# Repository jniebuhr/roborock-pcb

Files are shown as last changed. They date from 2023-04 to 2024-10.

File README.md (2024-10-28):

# Roborock CPAP PCB


[][cc-by-nc-sa]

This repository contains a custom PCB for use with the awesome work at [Roborock CPAP](https://github.com/condottab/Roborock-CPAP). The PCB shields the controller board from any back flow that might occur from the brushless controller.

The logic is the same as in the work of [stas2z](https://github.com/stas2z) but reshaped to better fit on the back of the blower while also allowing
for a cooling fan to be added.

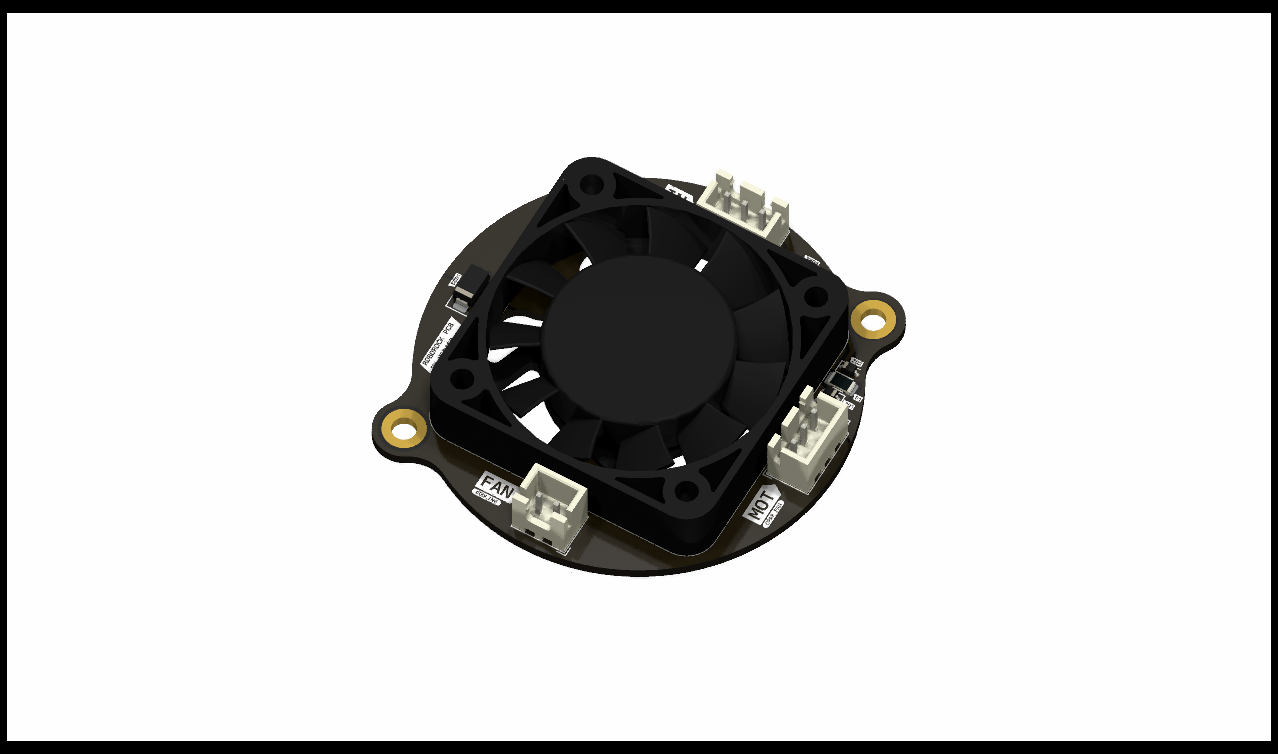
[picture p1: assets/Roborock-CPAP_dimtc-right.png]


## Assembly

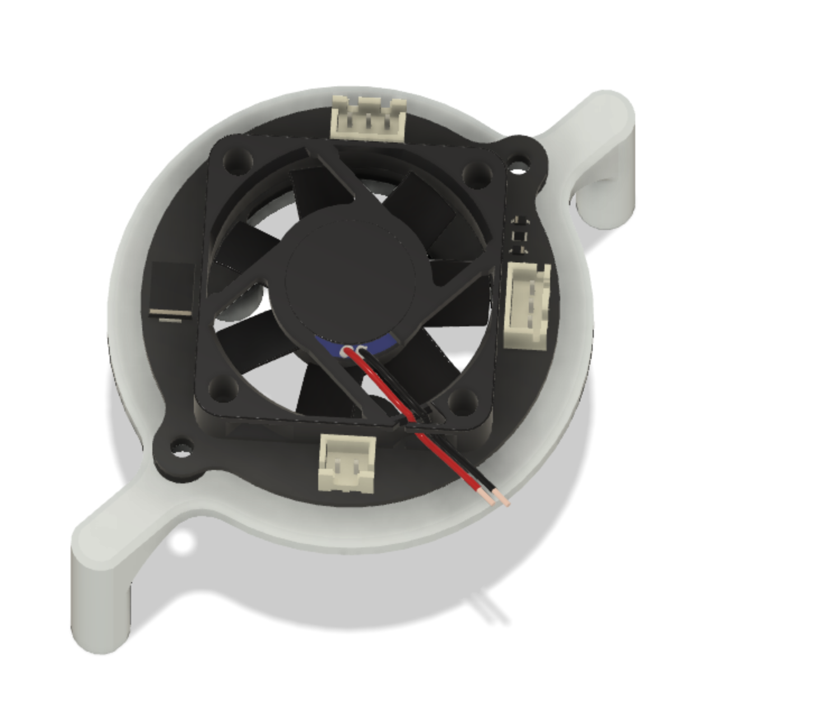
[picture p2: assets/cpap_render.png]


## BOM

| Quantity | Designation | Description |
|---|---|---|
| 1 | SHOTTKY2 | SS34 Diode |
| 2 | SHOTTKY1 | SS54 Diode |
| 1 | ZENER1, ZENER2 | BZT52C5V1S Diode |
| 1 | R2 | 1206 10kΩ resistor |
| 1 | R1 | 1206 1kΩ resistor |
| 2 | J1, J2 | JST XH 3P 2.54mm |
| 1 | J3 | JST XH 2P 2.54mm |
| 1 | - | 4010 cooling fan 24V |
| 2 | - | M3x6 |
| 4 | - | M3x12 |
| 4 | - | M3 hex nut |
| 4 | - | M3 heat set insert |

## Pinout

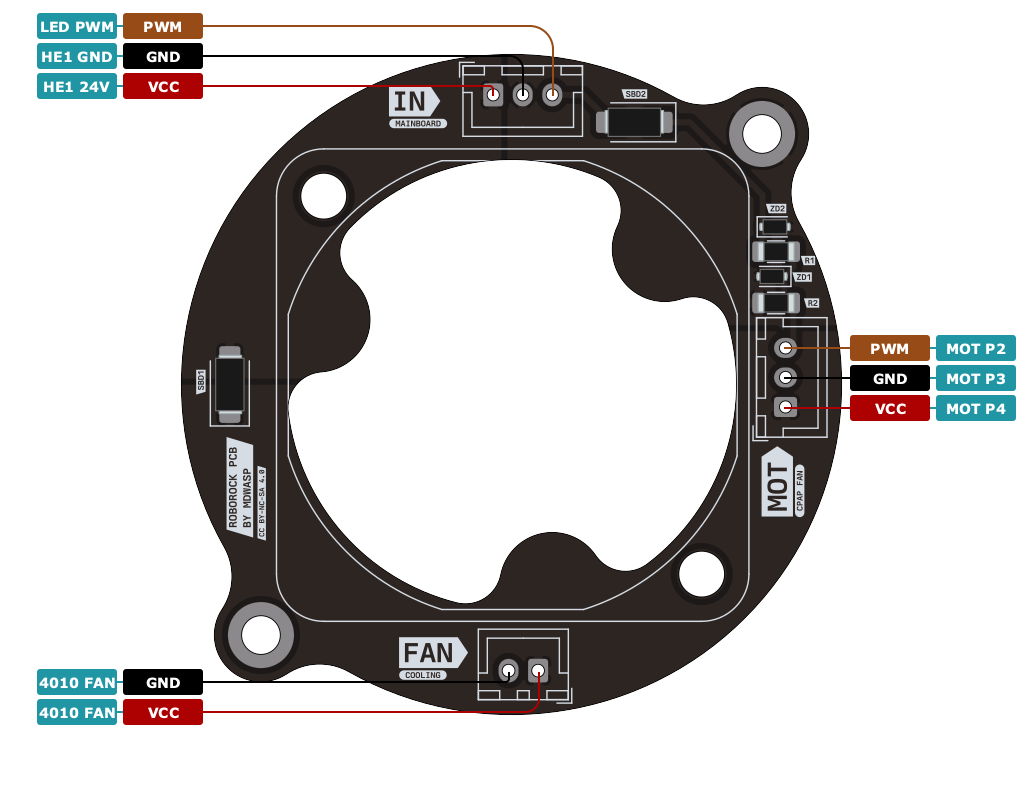
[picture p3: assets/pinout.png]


The pinout can also be found on the back side of your board and may be different from the most recent version (see note below). 

**Attention:**  
This motor pinout changed in version 0.2.0 due to a rotation of a connector. The same cables will work though since the connector has only been rotated. Refer to the writing on the back of your board.
In version 0.2.0, the 2 pin fan connector was labeled with switched GND and VCC.

## Ordering

In order to support this project, please consider ordering it through my affiliate link.

<a href="https://www.pcbway.com/project/shareproject/Roborock_CPAP_PCB_dc4ef951.html">PCB from PCBWay</a>

The gerber and BOM/CPL files can be found under `kicad/`.

## Mounting options

I have also developed some additional mounting options for the Roborock Fan:

* [VzBot 235](mounting/vzbot-235)
* more coming soon...

## Sponsors

The development of this board was kindly supported by [PCBWay](https://www.pcbway.com/) who sent me some prototypes of these boards free of charge.

## License

This work is licensed under a
[Creative Commons Attribution-NonCommercial-ShareAlike 4.0 International License][cc-by-nc-sa].

[][cc-by-nc-sa]

[cc-by-nc-sa]: http://creativecommons.org/licenses/by-nc-sa/4.0/
[cc-by-nc-sa-image]: https://licensebuttons.net/l/by-nc-sa/4.0/88x31.png
[cc-by-nc-sa-shield]: https://img.shields.io/badge/License-CC%20BY--NC--SA%204.0-lightgrey.svg?style=for-the-badge

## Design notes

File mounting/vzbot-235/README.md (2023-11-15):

# VzBot 235 exhaust mounting

This repurposes the default exhaust cutouts in the backplate to hold your Roborock fan. One side is used for the intake, the other side passes through the hose.

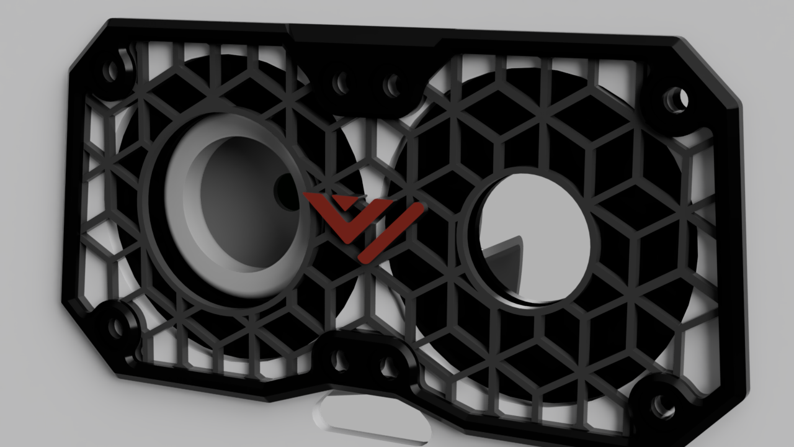
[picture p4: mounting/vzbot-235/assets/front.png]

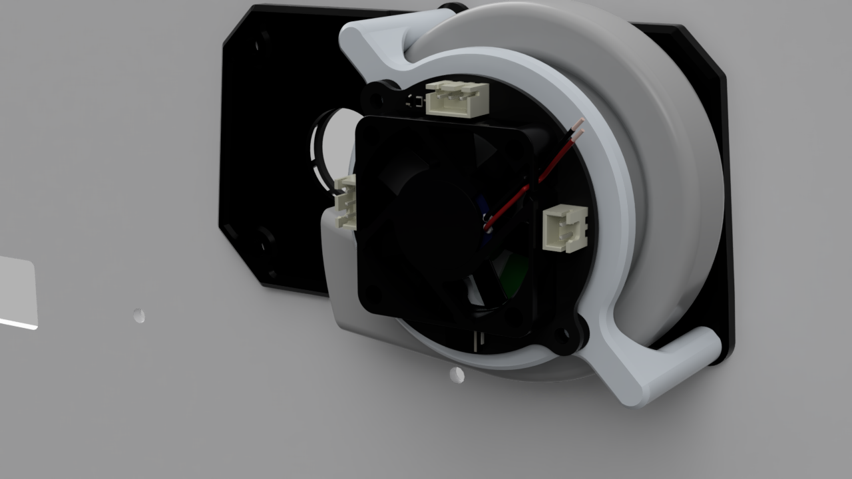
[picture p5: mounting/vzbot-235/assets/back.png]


## BOM

| Quantity | Description |
|---|---|
| 8 | M3x12 SHCS |
| 8 | M3 heat set insert |
| 2 | M3x6 SHCS |
| 1 | Roborock Fan Assembly |

## Printing

Files can be found in [stls/](stls/)

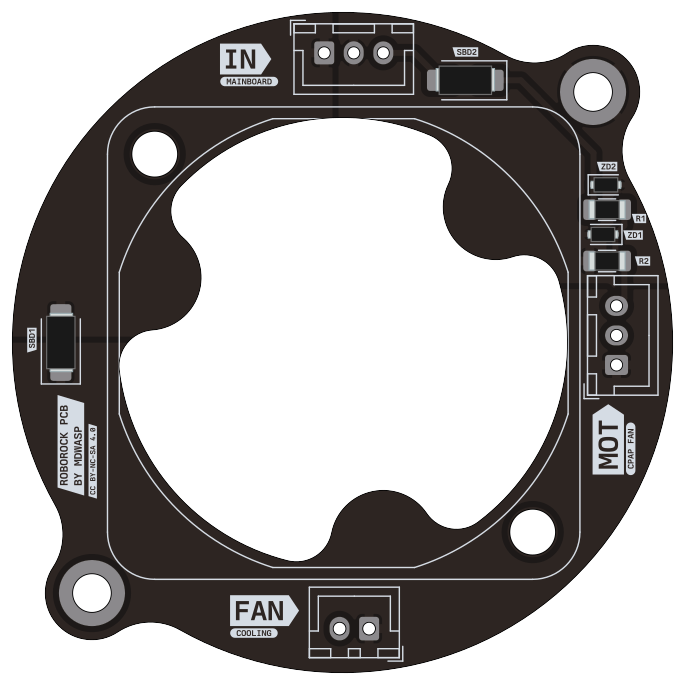
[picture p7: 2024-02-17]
assets/Roborock-CPAP_top.png

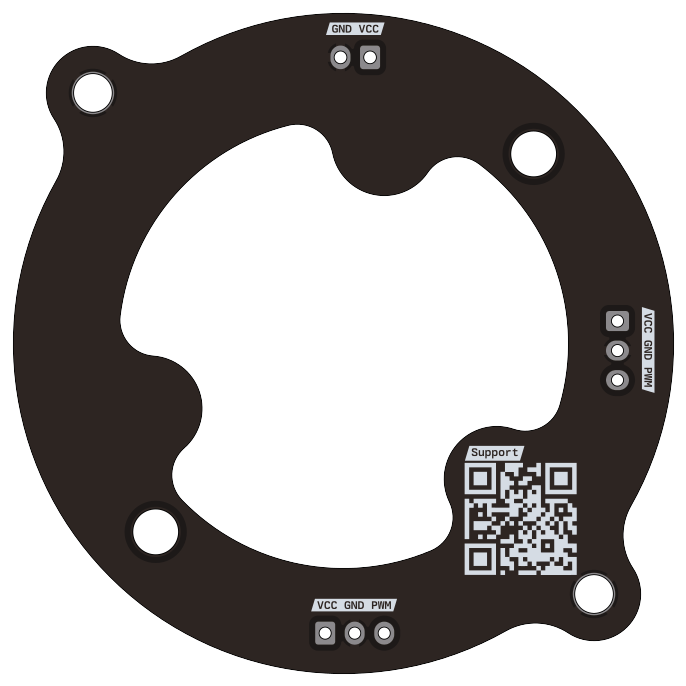
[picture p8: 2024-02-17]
assets/Roborock-CPAP_bottom.png

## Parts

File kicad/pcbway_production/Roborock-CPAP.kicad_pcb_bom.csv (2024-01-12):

designator | quantity | value | pack | mpn | mount_type
FAN1 | 1 | Axial fan 40mm | Axial fan 40mm |  | tht
H1, H2 | 2 | BoardMount_Pad | MountingHole_3.2mm_M3_DIN965_Pad_TopOnly |  | tht
J1 | 1 | INPUT | JST_XH_B3B-XH-A_1x03_P2.50mm_Vertical |  | tht
J2 | 1 | MOTOR | JST_XH_B3B-XH-A_1x03_P2.50mm_Vertical |  | tht
J3 | 1 | FAN | JST_XH_B2B-XH-A_1x02_P2.50mm_Vertical |  | tht
R1 | 1 | 1K | R_1206_3216Metric |  | smt
R2 | 1 | 10K | R_1206_3216Metric |  | smt
SBD1 | 1 | SS54 | D_SMA |  | smt
SBD2 | 1 | SS34 | D_SMA |  | smt
ZD1, ZD2 | 2 | BZT52C5V1S | D_SOD-323 |  | smt
kibuzzard-658C2196 | 1 | G*** | kibuzzard-658C2196 |  | tht
kibuzzard-658C21F4 | 1 | G*** | kibuzzard-658C21F4 |  | tht
kibuzzard-658C2284 | 1 | G*** | kibuzzard-658C2284 |  | tht
kibuzzard-658C22D5 | 1 | G*** | kibuzzard-658C22D5 |  | tht
kibuzzard-658C2303 | 1 | G*** | kibuzzard-658C2303 |  | tht
kibuzzard-658C2312 | 1 | G*** | kibuzzard-658C2312 |  | tht
kibuzzard-658C2324 | 1 | G*** | kibuzzard-658C2324 |  | tht
kibuzzard-658C2360 | 1 | G*** | kibuzzard-658C2360 |  | tht
kibuzzard-658C236E | 1 | G*** | kibuzzard-658C236E |  | tht
kibuzzard-658C23C6 | 1 | G*** | kibuzzard-658C23C6 |  | tht
kibuzzard-658C23F8 | 1 | G*** | kibuzzard-658C23F8 |  | tht
kibuzzard-658C2410 | 1 | G*** | kibuzzard-658C2410 |  | tht
kibuzzard-658C47D4 | 1 | G*** | kibuzzard-658C47D4 |  | tht
kibuzzard-659E6D3A | 1 | G*** | kibuzzard-659E6D3A |  | tht
kibuzzard-659E705B | 1 | G*** | kibuzzard-659E705B |  | tht
kibuzzard-659E706B | 1 | G*** | kibuzzard-659E706B |  | tht
kibuzzard-659FE543 | 1 | G*** | kibuzzard-659FE543 |  | tht
kibuzzard-659FE8A4 | 1 | G*** | kibuzzard-659FE8A4 |  | tht

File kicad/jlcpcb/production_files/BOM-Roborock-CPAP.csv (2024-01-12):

Comment | Designator | Footprint | LCSC
10K | R2 | R_1206_3216Metric | C17902
SS54 | SBD1 | D_SMA | C22452
BZT52C5V1S | ZD1,ZD2 | D_SOD-323 | C2910089
1K | R1 | R_1206_3216Metric | C4410
SS34 | SBD2 | D_SMA | C8678
MOTOR | J2 | JST_XH_B3B-XH-A_1x03_P2.50mm_Vertical
INPUT | J1 | JST_XH_B3B-XH-A_1x03_P2.50mm_Vertical
FAN | J3 | JST_XH_B2B-XH-A_1x02_P2.50mm_Vertical

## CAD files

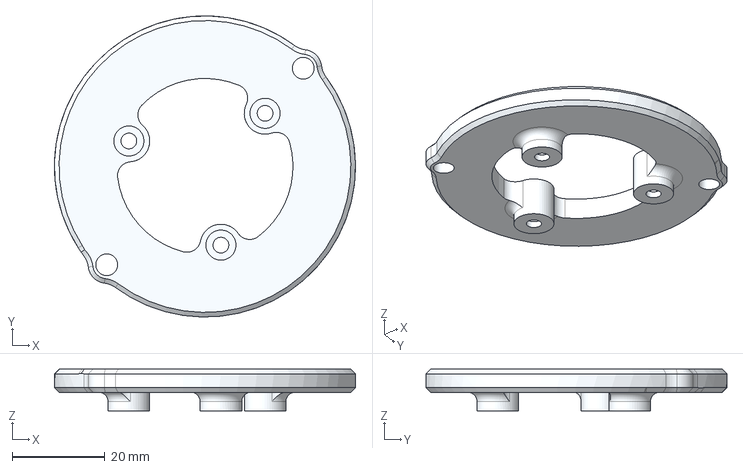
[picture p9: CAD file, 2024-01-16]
cad/mount_plate_nidec.step
65.0 x 65.0 x 9.00 mm

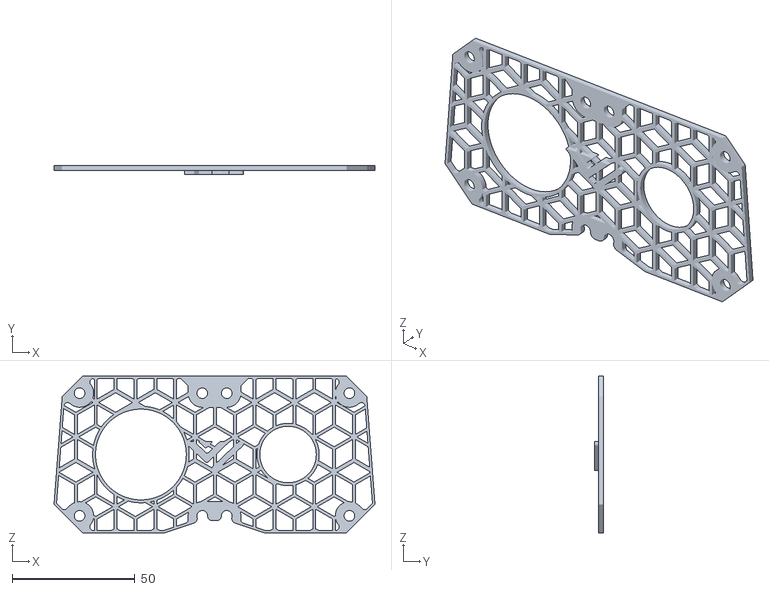
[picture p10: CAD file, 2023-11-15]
mounting/vzbot-235/stls/[a]_vz_cpap_insert.stl
130.9 x 3.50 x 64.0

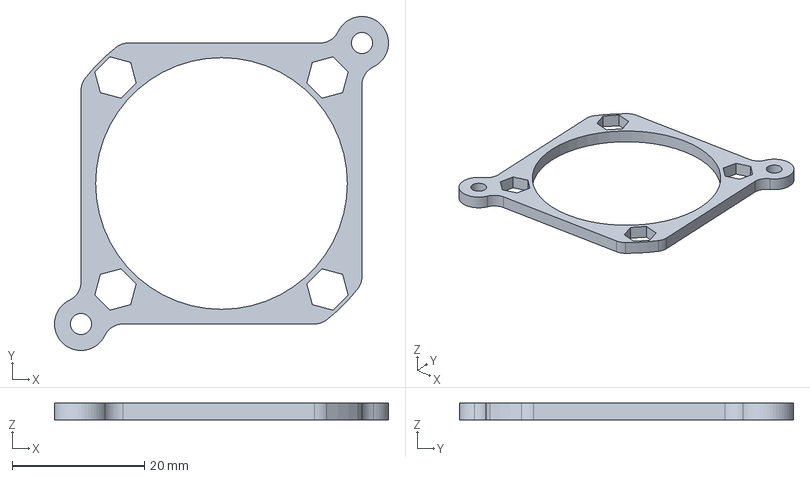
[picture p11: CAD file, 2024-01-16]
cad/spacer.step
50.4 x 50.4 x 2.50 mm

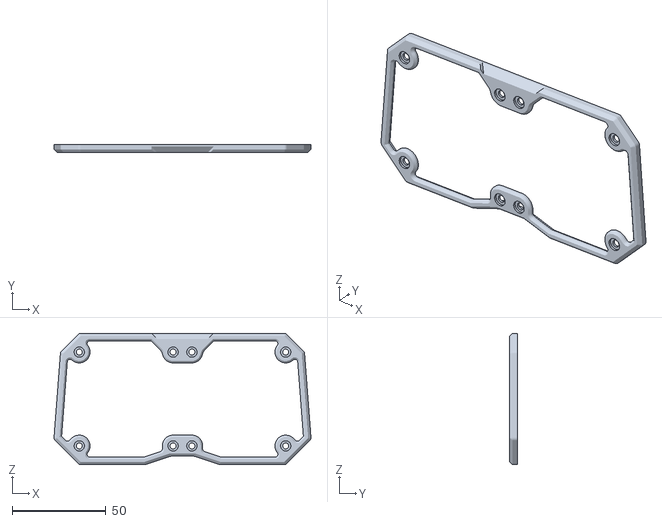
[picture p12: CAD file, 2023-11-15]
mounting/vzbot-235/stls/vz_cpap_guard.stl
136.9 x 4.00 x 70.0

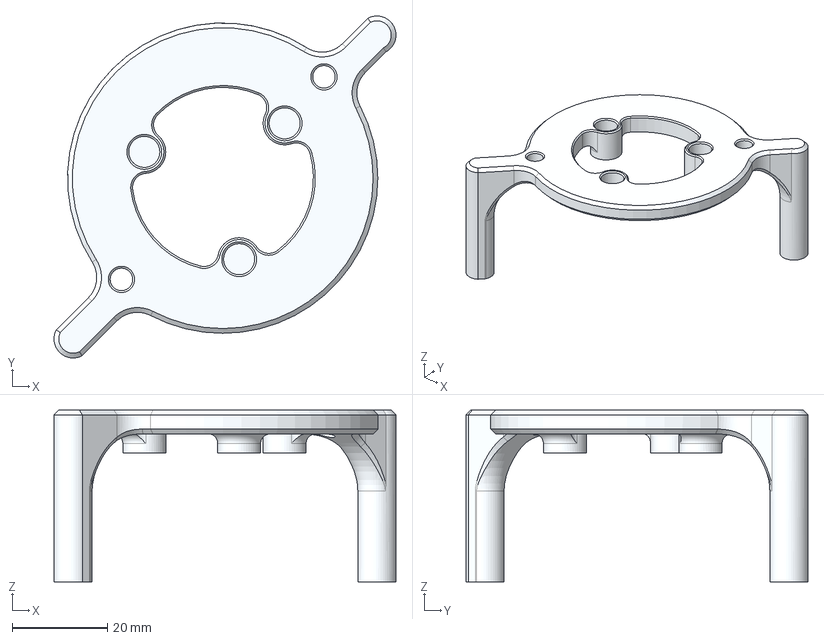
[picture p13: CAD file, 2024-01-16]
cad/mount_plate.step
71.6 x 71.6 x 36.0 mm

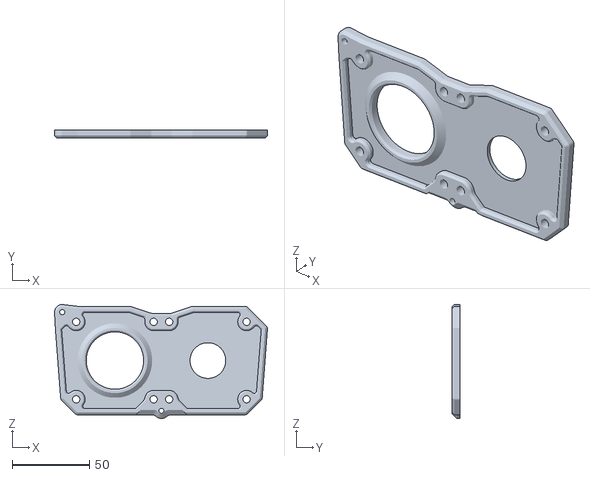
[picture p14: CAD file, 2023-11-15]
mounting/vzbot-235/stls/vz_cpap_backplate.stl
137.5 x 5.00 x 73.6

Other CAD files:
stls/mount_plate.stl
stls/mount_plate_nidec.stl
stls/spacer.stl

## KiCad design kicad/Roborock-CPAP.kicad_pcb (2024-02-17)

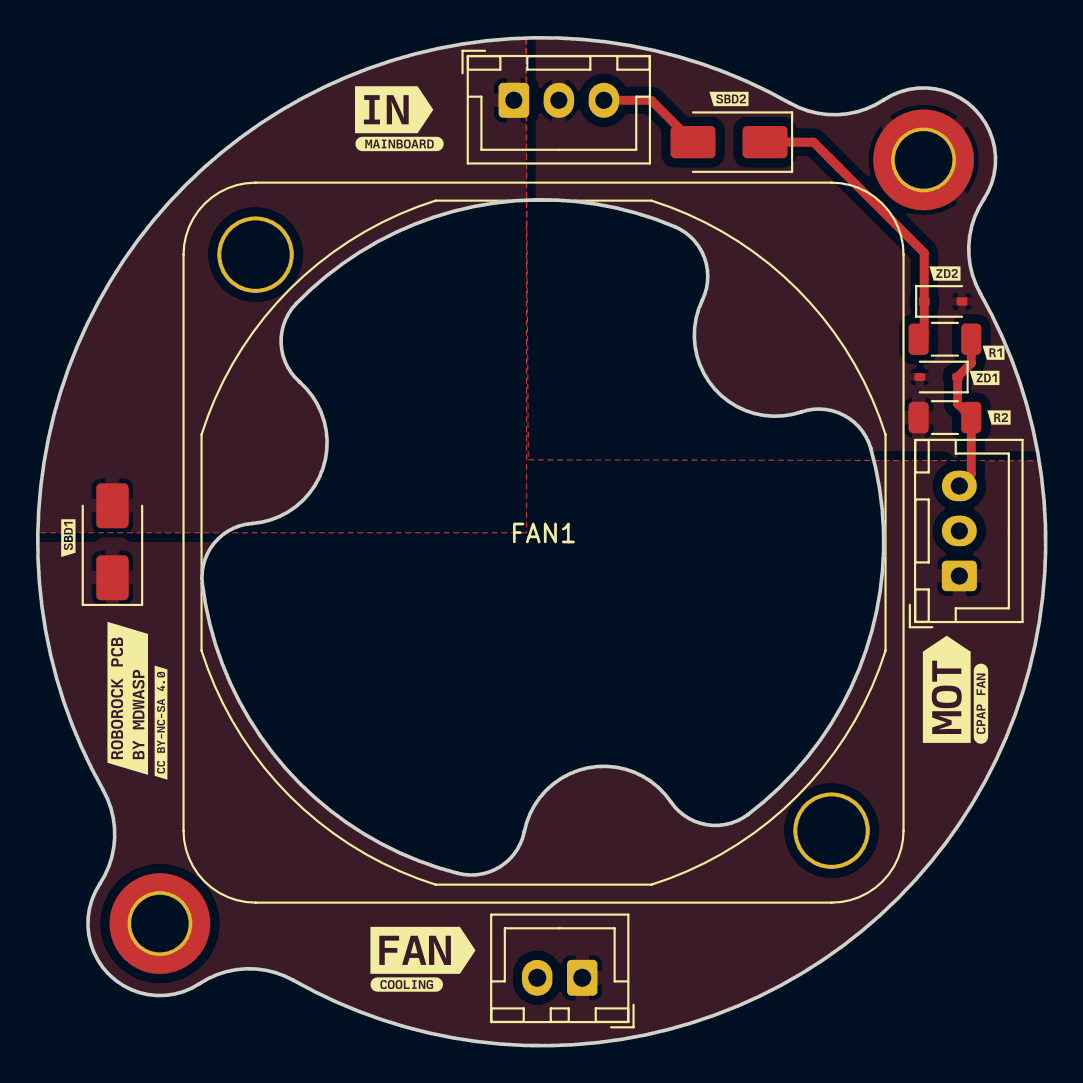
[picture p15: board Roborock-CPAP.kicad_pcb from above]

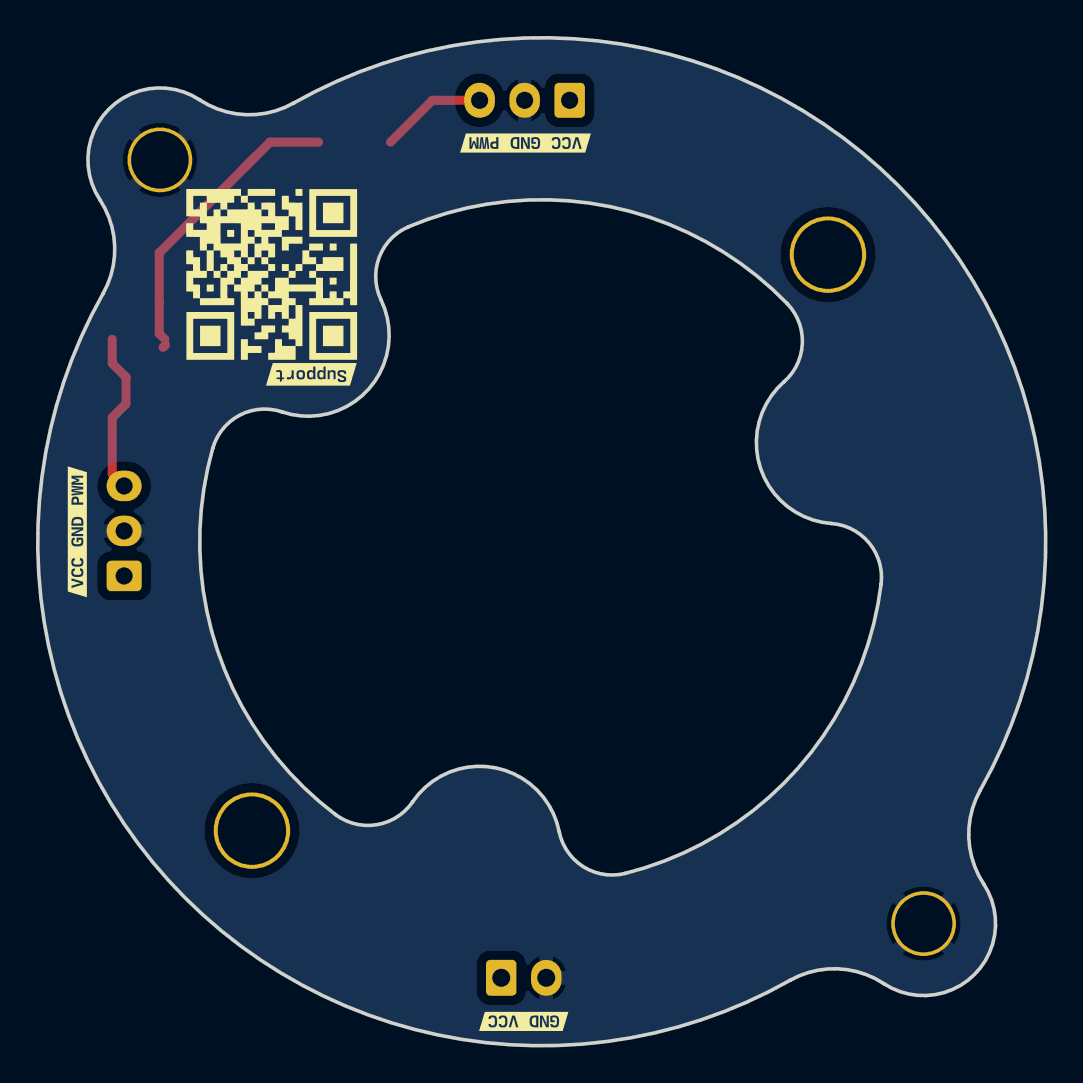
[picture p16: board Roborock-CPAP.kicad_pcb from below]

Board: 2 copper layers, 56.0 x 56.0 mm, 30 parts (4 on the bottom side), 6 nets.

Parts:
FAN1: Axial fan 40mm
H1, H2: BoardMount_Pad; MountingHole_3.2mm_M3_DIN965_Pad_TopOnly
J1: INPUT; JST_XH_B3B-XH-A_1x03_P2.50mm_Vertical
J2: MOTOR; JST_XH_B3B-XH-A_1x03_P2.50mm_Vertical
J3: FAN; JST_XH_B2B-XH-A_1x02_P2.50mm_Vertical
R1: 1K; R_1206_3216Metric
R2: 10K; R_1206_3216Metric
SBD1: SS54; D_SMA
SBD2: SS34; D_SMA
ZD1, ZD2: BZT52C5V1S; D_SOD-323
kibuzzard-65D0EC22: G***; kibuzzard-65D0EC22
kibuzzard-658C21F4: G***; kibuzzard-658C21F4
kibuzzard-658C22D5: G***; kibuzzard-658C22D5
kibuzzard-658C23C6: G***; kibuzzard-658C23C6
kibuzzard-658C23F8: G***; kibuzzard-658C23F8
kibuzzard-658C47D4: G***; kibuzzard-658C47D4
kibuzzard-658C236E: G***; kibuzzard-658C236E
kibuzzard-658C2196: G***; kibuzzard-658C2196
kibuzzard-658C2284: G***; kibuzzard-658C2284
kibuzzard-658C2303: G***; kibuzzard-658C2303
kibuzzard-658C2312: G***; kibuzzard-658C2312
kibuzzard-658C2324: G***; kibuzzard-658C2324
kibuzzard-658C2360: G***; kibuzzard-658C2360
kibuzzard-658C2410: G***; kibuzzard-658C2410
kibuzzard-659E705B: G***; kibuzzard-659E705B
kibuzzard-659E706B: G***; kibuzzard-659E706B
kibuzzard-659FE8A4: G***; kibuzzard-659FE8A4
kibuzzard-659FE543: G***; kibuzzard-659FE543

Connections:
GND: H1.1, H2.1, H2.2 (1), J1.2, J2.2, J3.2, R2.2, ZD1.2 (A), ZD2.2 (A)
unnamed: R1.2, SBD2.1 (K), ZD2.1 (K)
PWM_IN: J1.3, SBD2.2 (A)
PWM_OUT: J2.3, R1.1, R2.1, ZD1.1 (K)
VCC: J1.1, SBD1.2 (A)
VCC_FUSED: J2.1, J3.1, SBD1.1 (K)

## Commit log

2023-04-16 Update BOM
2023-05-05 Add Nidec mount plate without feet
    [mount_plate_nidec.stl]
2023-11-07 Component spacing, extra text
    Spaced components a little more evenly so their descriptors are coherent and easy to read
    Added extra clarifying text to the connectors on the left side
    [Roborock-CPAP.kicad_sch]
2023-11-07 Flood zones (VCC, GND) now follow board outline
    [Roborock-CPAP.kicad_pcb]
2023-11-07 Increase clearance between schottky diode track and screw hole
    using track guidance and fillets
    [Roborock-CPAP.kicad_pcb]
2023-11-07 Extra connector clarification
    [Roborock-CPAP.kicad_pcb]
2023-11-07 Mounting hole pads
    Added appropriate quantity of mounting hole pads
    Also groups the fan & mounting holes
    [Roborock-CPAP.kicad_sch]
2023-11-07 Board to Roborock holes as THT
    Also renames this group as "Board to Roborock"
2023-11-07 More reference designator fixes
    Fixes some hole reference designators
    Swaps the long designators for shorthands like SBD, ZD
    [Roborock-CPAP.kicad_pcb, Roborock-CPAP.kicad_sch]
2023-11-07 Add fan connection example
    [Roborock-CPAP.kicad_sch]
2023-11-07 Resolve ERC (rule checker) errors/warnings
    [Roborock-CPAP.kicad_sch]
2023-11-07 Rotated fan header right side up, fan example wire colours
    Cooling fan header had pin order 2-1, being reversed. Reversed this along with example fan; Gave example fan wires red/black colouring
    [Roborock-CPAP.kicad_sch]
2023-11-07 Further refine fan holes
    Oval holes at 1mm lateral-diagonal tolerance
    custom footprint created to edit them separately from the corner holes
    may put the fan holes into a custom footprint that has all four of 'm in one footprint
    [Roborock-CPAP.kicad_sch]
2023-11-08 More pad optimizations, add colours to nets
    [Roborock-CPAP.kicad_pcb]
2023-11-08 Image renders of PCB
2023-11-11 feat: Change filled zones, replace diode part number, update docs
    [BOM-Roborock-CPAP.csv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]
2023-11-11 Fine tune ground plane, rotate connector
    Also adds 0.5mm tracks as the standard track width, and adds a new net class for power tracks that could be useful in the future
    [Roborock-CPAP.kicad_pcb]
2023-11-11 feat: Regenerate screenshots, fix diode number
    [BOM-Roborock-CPAP.csv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]
2023-11-11 Create KiCad .gitignore
    Ignores temporary and backup files made by KiCad
2023-11-11 feat: Add new pinout
    [Roborock-CPAP.kicad_pcb]
2023-11-12 Add 40mm fan
    + remove the four corner pads from the schematic;
    + exclude fan from BOM
    + add fan model (https://grabcad.com/library/40x40x10mm-brushless-axial-fan-1)
2023-11-12 Add Fan1 to schematic, pcb; fix DRC violations of fan etc; update pcb from schematic
    [Roborock-CPAP.kicad_pcb, Roborock-CPAP.kicad_sch]
2023-11-15 feat: Add vzbot 235 mounting option
    [[a]_vz_cpap_insert.stl, vz_cpap_backplate.stl, vz_cpap_guard.stl]
2023-12-27 Deleted Unnecesarry files for push
    [BOM-Roborock-CPAP.csv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]
2023-12-27 Added new version files
    [Roborock-CPAP.kicad_pcb, Roborock-CPAP.kicad_sch]
2023-12-27 Moved files to jlcpcb folder
    [BOM-Roborock-CPAP.csv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]
2023-12-27 Upload gerber files
    [Roborock-CPAP-CuBottom.gbr, Roborock-CPAP-CuTop.gbr, Roborock-CPAP-EdgeCuts.gbr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]
2023-12-27 Fixed resistor footprint
    [BOM-Roborock-CPAP.csv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]
2023-12-27 changed resistor footprint name in readme
2024-01-12 fix: Rework some labels
    [BOM-Roborock-CPAP.csv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]
2024-01-16 feat: Add cad files for mount
    [mount_plate.step, mount_plate_nidec.step, spacer.step]
2024-02-17 feat: Add new workflows for image generation, pinout
    [Roborock-CPAP.kicad_pcb]

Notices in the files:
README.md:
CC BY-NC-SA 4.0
